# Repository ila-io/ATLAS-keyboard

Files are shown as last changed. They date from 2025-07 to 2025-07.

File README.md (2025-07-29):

# ATLAS-keyboard
A custom low profile split keyboard designed for hack club highway! It has 33 keys on each side for a total of 66, and uses one these awesome open source [mouse wheel style encoders](https://github.com/Taro-Hayashi/THQWGD0010) by Taro Hayashi on each side for navigating text (they act as arrow keys, with the one on the left as an up and down, and the one on the right is left and right). The case also has a super minimal and low profile plateless design with no top frame that leaves the cool part of the PCB uncovered, and keeps the keys nice and low on my desk. It also features a system for creating adjustable tenting angles, which is nice because I'd like to find what works best for me comfort-wise! 
i named it atlas becasue umm uhh it'll help me with text navigation? (ok this is a stretch, i just like the word) 

# Overview
In exploring split keyboard layouts, I found that not many of them had all the keys that I wanted, and the ones that did had crazy layouts and sizes. I struck a balance between the two, minimizing the size of my keyboard by making it as low profile as possible and limiting it to only the keys that I wanted.

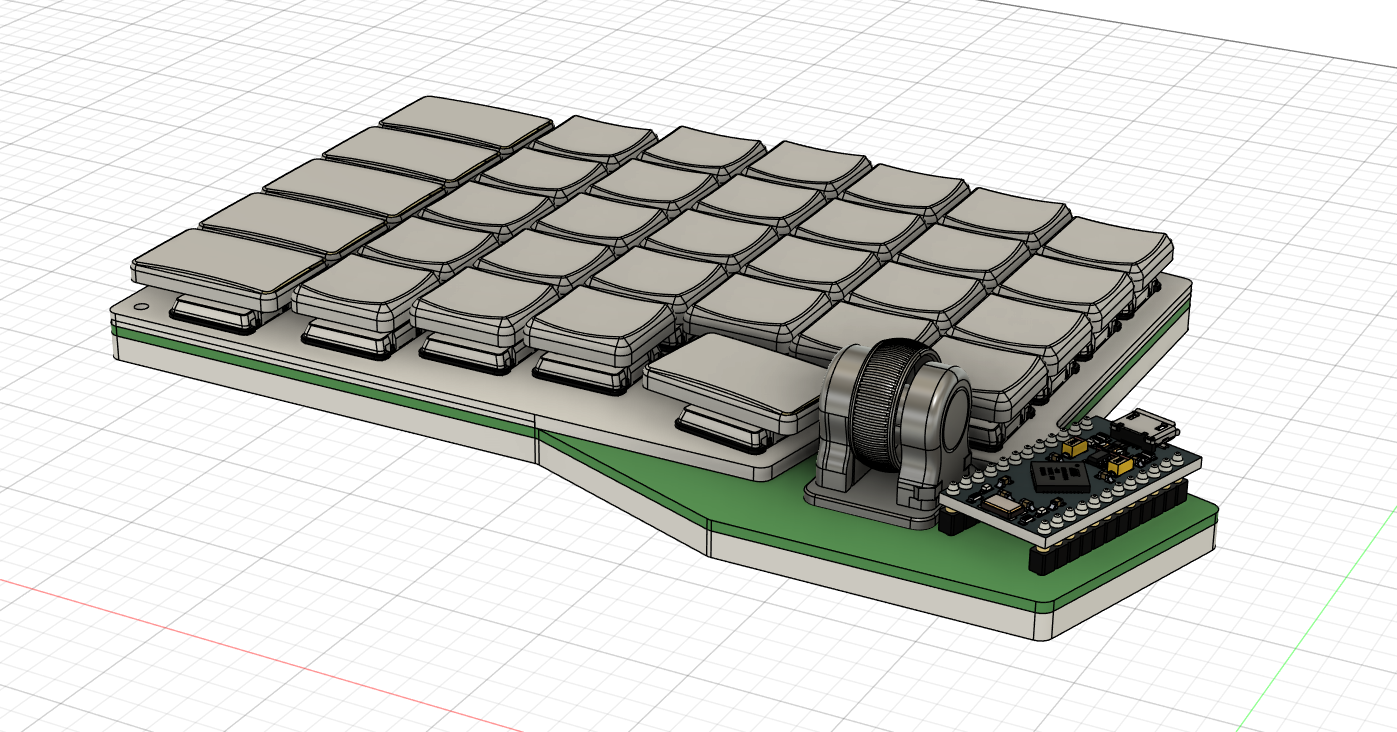
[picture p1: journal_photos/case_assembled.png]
photo of full keyboard

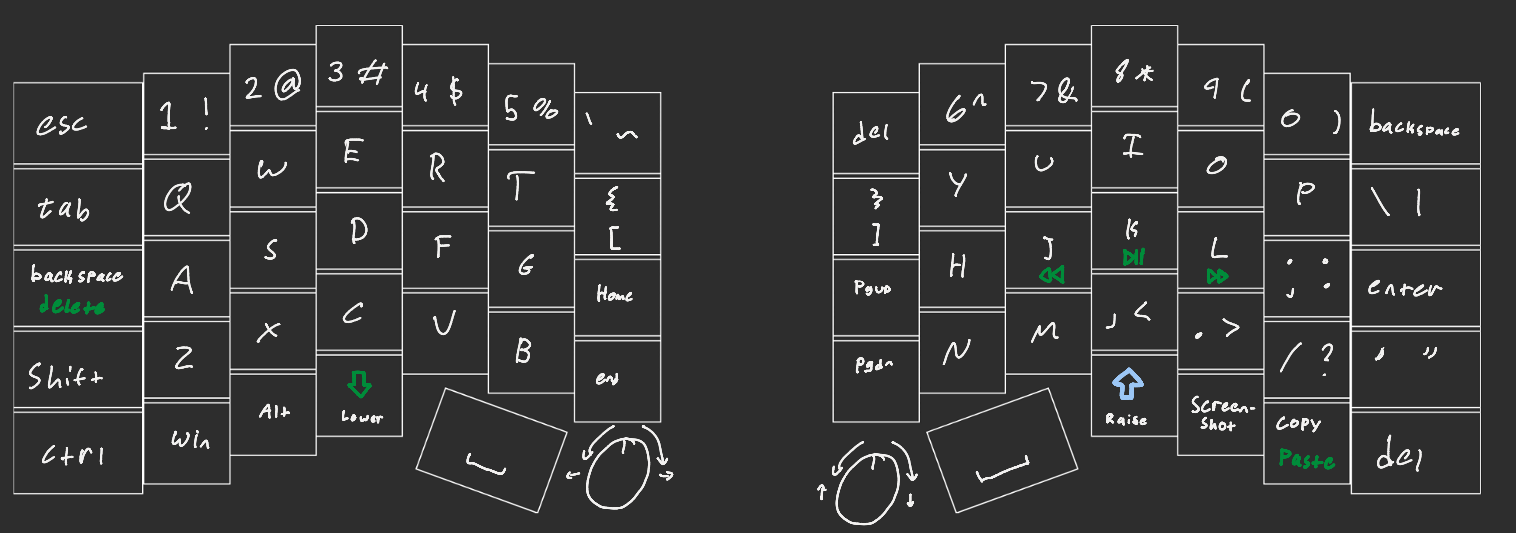
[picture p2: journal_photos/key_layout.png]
photo of keyboard layout

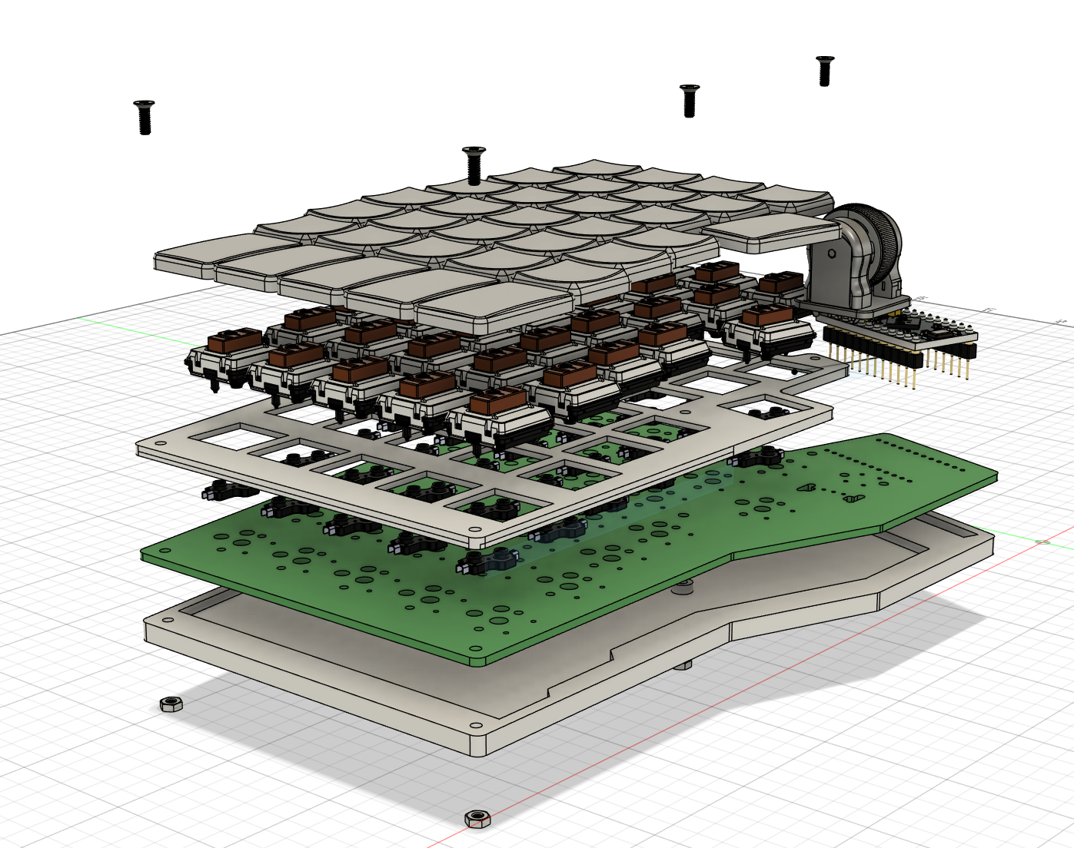
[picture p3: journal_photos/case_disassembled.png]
photo of full keyboard disassembled

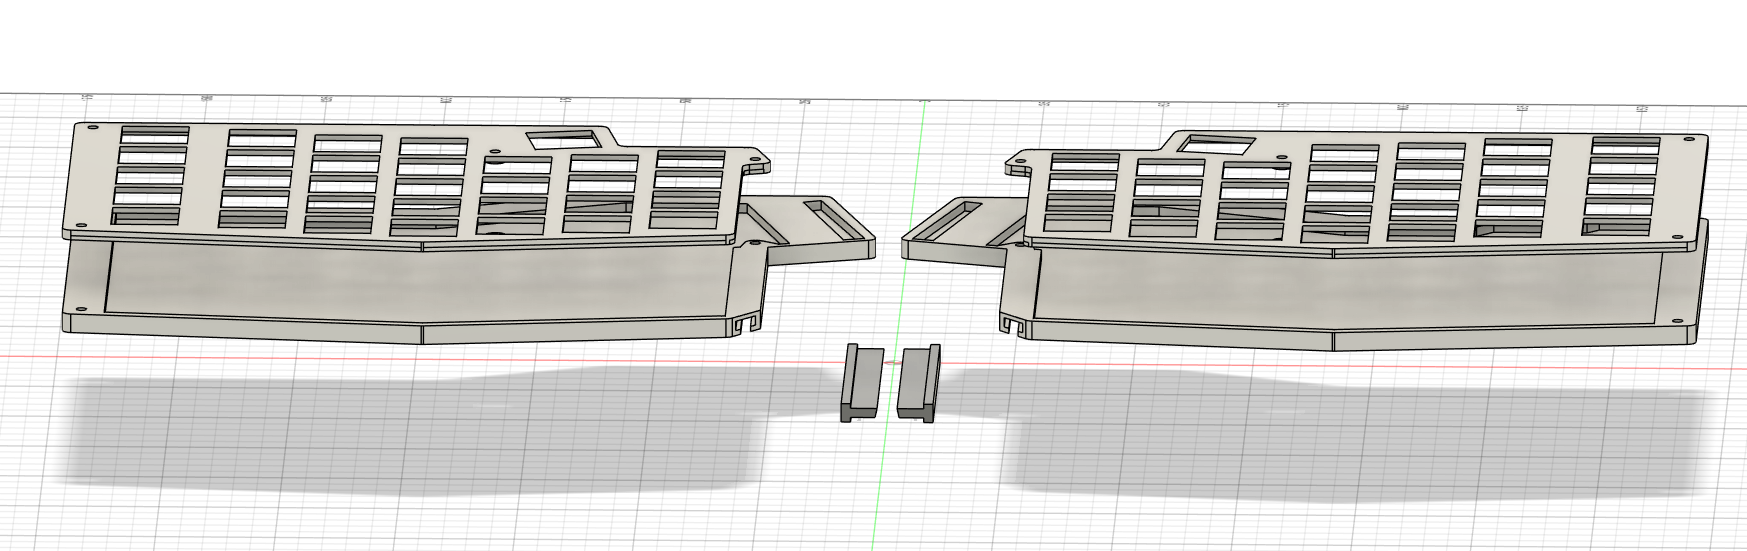
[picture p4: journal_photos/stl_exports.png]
photo of parts to print

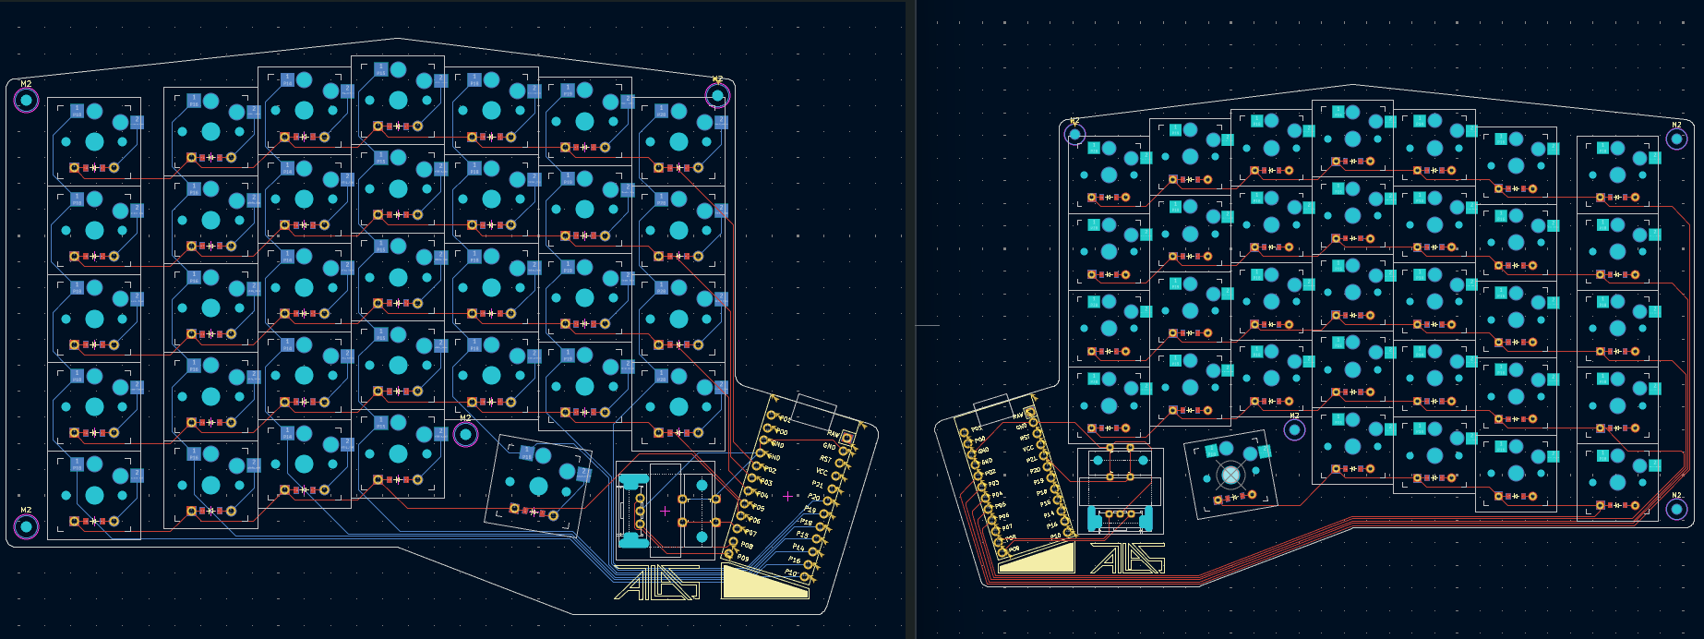
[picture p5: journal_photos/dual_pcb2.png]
photo of left and right PCBs

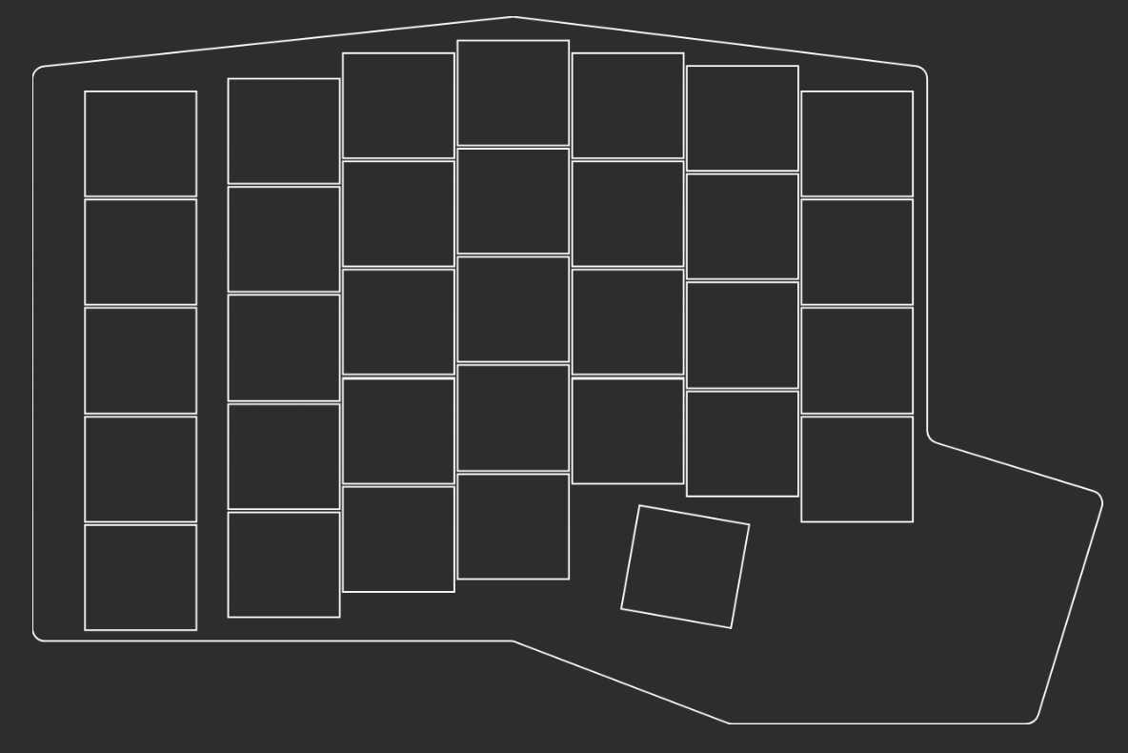
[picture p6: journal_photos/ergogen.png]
photo of ergogen generation

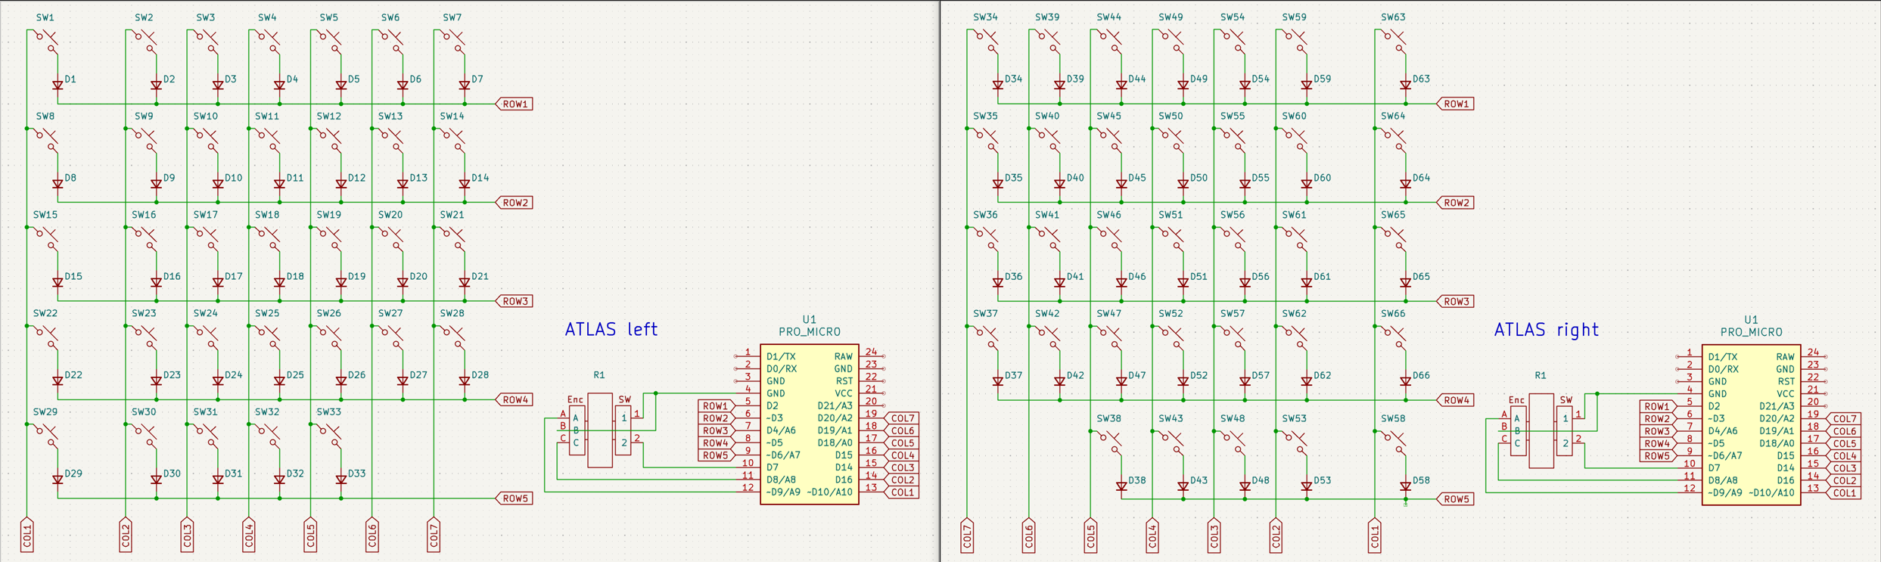
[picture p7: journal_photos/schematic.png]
photo of schematic

### NOTE:
PCB designs are based off of the PCB files/config.yaml Ergogen file, schematics are only used as reference.

## BOM 

|Item |Count|Total Cost|Source |Link |Notes |
|---|-----|---|---|---|---|
|Choc 1u Keycaps x10 |6 |$21.00 |typeractive|https://typeractive.xyz/products/mbk-keycaps?variant=45419753111783  | |
|Choc 1.5u Keycaps x2 |6 |$9.00 |typeractive|https://typeractive.xyz/products/mbk-keycaps?variant=48512019333351  | |
|Choc v1 Red Switches x10 |8 |$44 |typeractive|https://typeractive.xyz/products/choc-switches?variant=45741919240423|A little more expensive than some alternatives, but free shipping brings it below all others|
|Kailh Low Profile Hotswap Sockets x100|1 |$0.99 |aliexpress |https://www.aliexpress.us/item/3256803389452947.html |First time discount |
|1N4148W SMD Diodes x100 |1 |$1.37 |aliexpress |https://www.aliexpress.com/item/3256806137153769.html | |
|M2x6mm screws x50 |1 |$1.74 |aliexpress |https://www.aliexpress.com/item/2255801062616407.html?mp=1 | |
|M2 Hex Nuts x50 |1 |$1.51 |aliexpress |https://www.aliexpress.com/item/3256807407546447.html?mp=1 | |
|6x6x7 Tactile Button Switch x100 |1 |$2.07 |aliexpress |https://www.aliexpress.com/item/3256803858853331.html?mp=1 | |
|11mm Mouse Encoder x10 |1 |$1.56 |aliexpress |https://www.aliexpress.com/item/3256801290854651.html?mp=1 | |
|left PCB x5 + right PCB x5 + shipping |1 |$29.65 |JLCPCB |https://www.jlcpcb.com/ | |
|Atmega32U4 Pro Micro Board Module x3  |1 |$19.88 |amazon |https://a.co/d/17oYyaQ |even though there are 3 of them, when considering shipping this is the best deal i could find on even 2 |
|Total: | |$132.77 | | | |

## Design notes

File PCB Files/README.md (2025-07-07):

# NOTE:
The .kicad_sch schematic files are for reference only, the PCB files are not directly pulled from them. They are generated by the config.yaml [ergogen](https://github.com/ergogen/ergogen) file

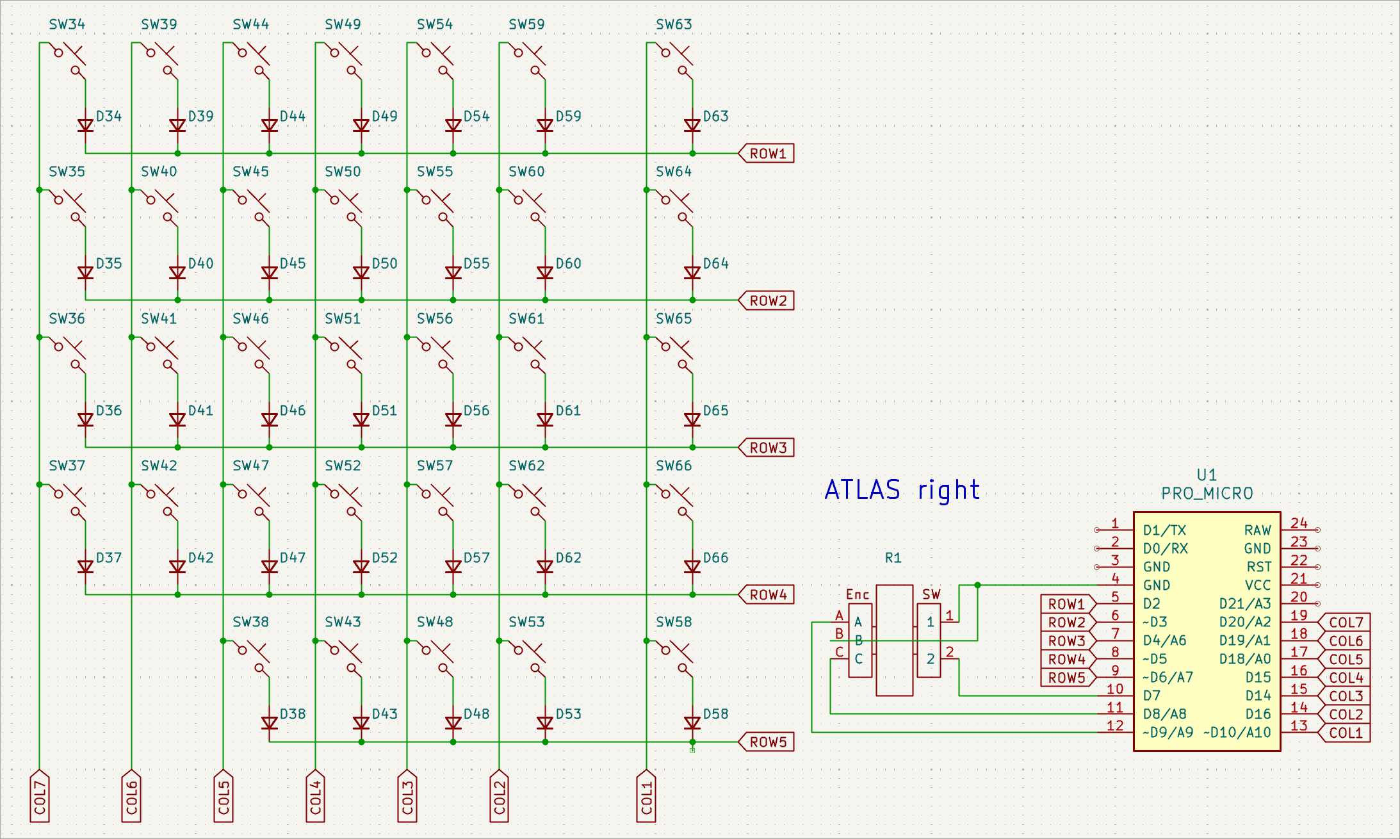
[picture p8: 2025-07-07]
journal_photos/schematic_right.png

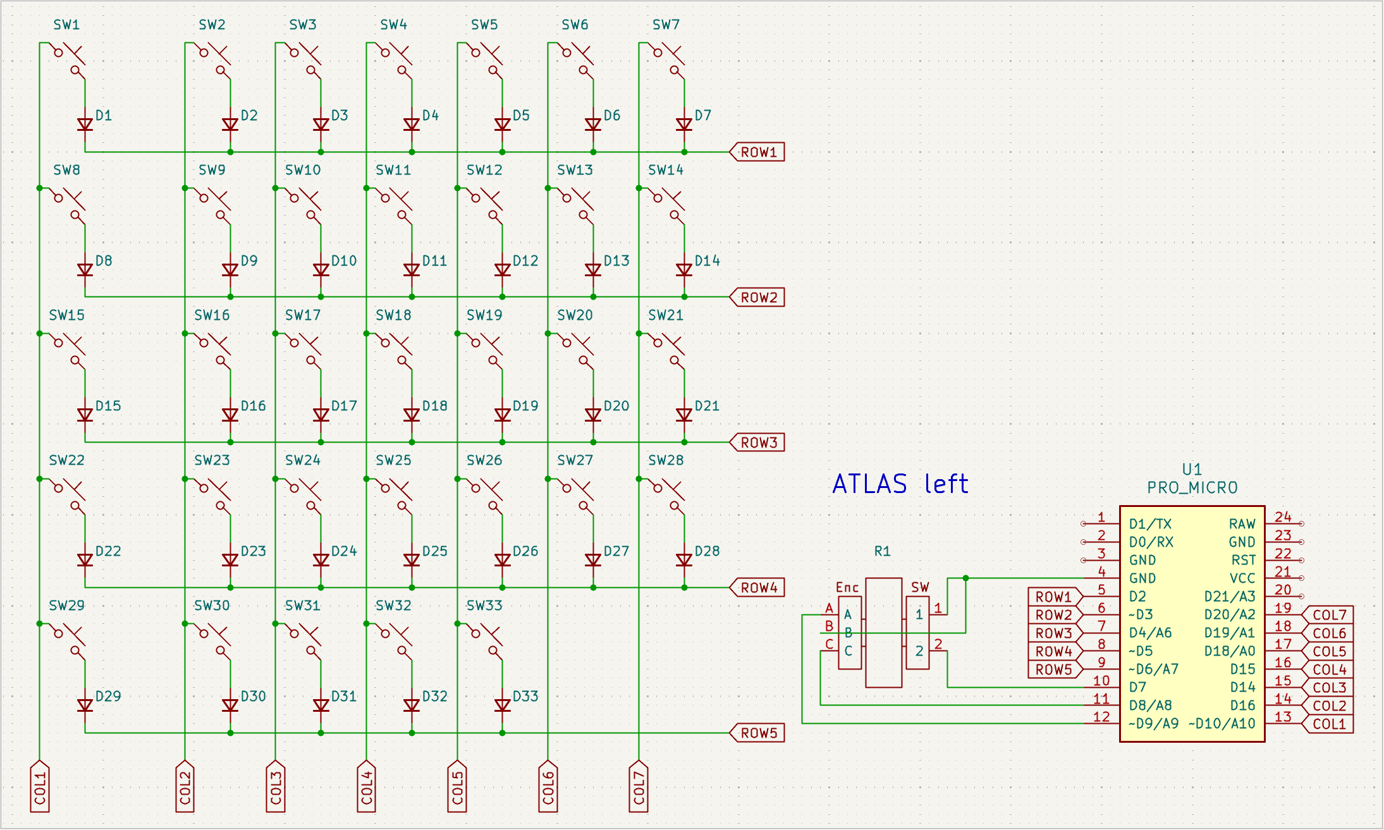
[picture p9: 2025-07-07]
journal_photos/schematic_left.png

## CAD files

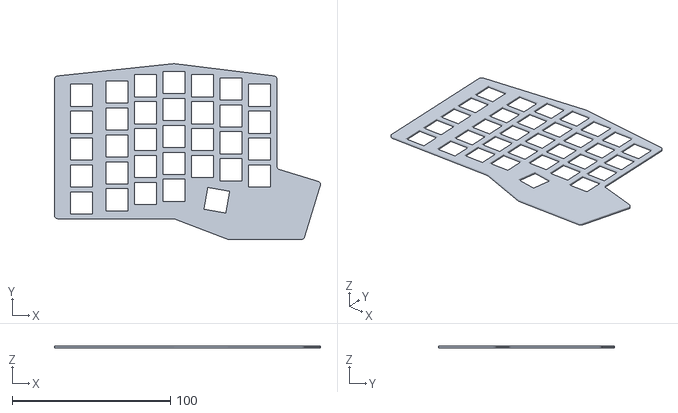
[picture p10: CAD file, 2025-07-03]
CAD Files/Components/plate.stl
168.0 x 111.0 x 1.20

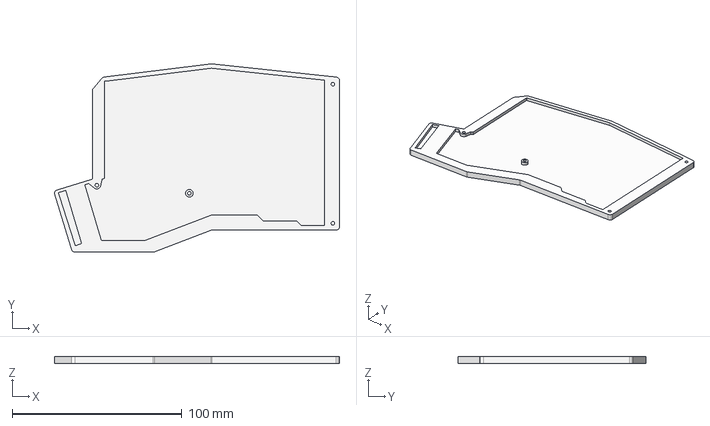
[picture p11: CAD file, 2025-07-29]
production/CAD/right_case.step
168.0 x 111.0 x 4.00 mm

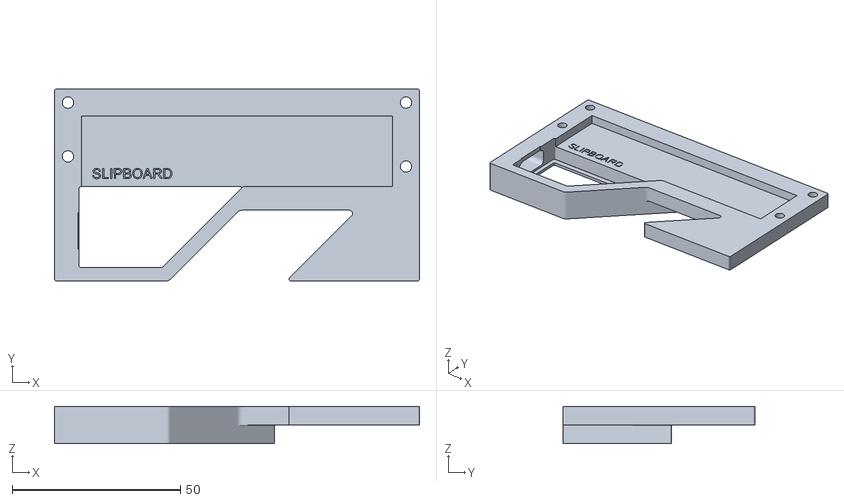
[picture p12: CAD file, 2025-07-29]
production/CAD/STLs/Case Base.stl
108.5 x 57.0 x 11.0

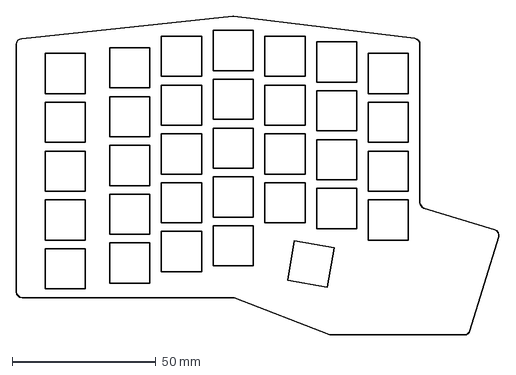
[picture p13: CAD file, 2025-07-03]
CAD Files/Components/key_cutouts.dxf
168.2 x 111.0 mm

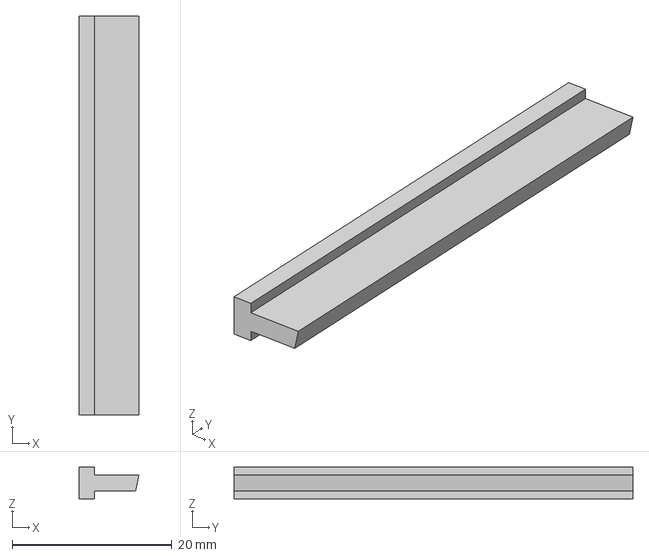
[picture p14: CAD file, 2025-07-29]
production/CAD/left_kickstand.step
7.50 x 50.0 x 3.96 mm

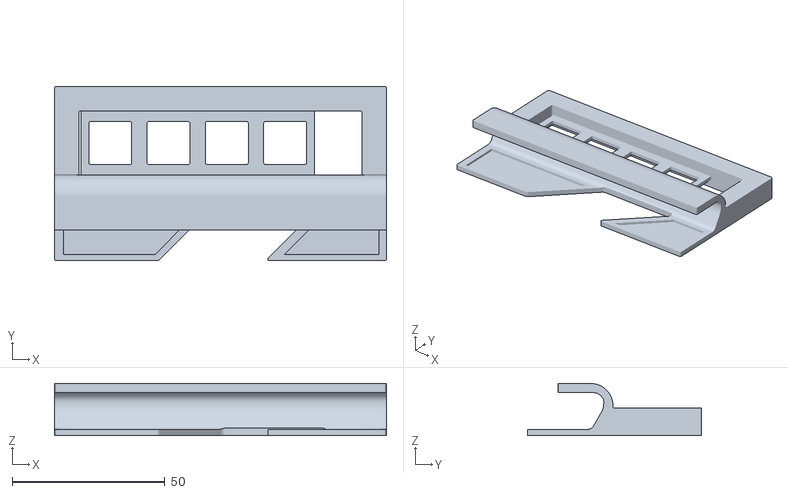
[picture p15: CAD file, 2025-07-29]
production/CAD/STLs/Case Top.stl
108.5 x 57.0 x 17.0

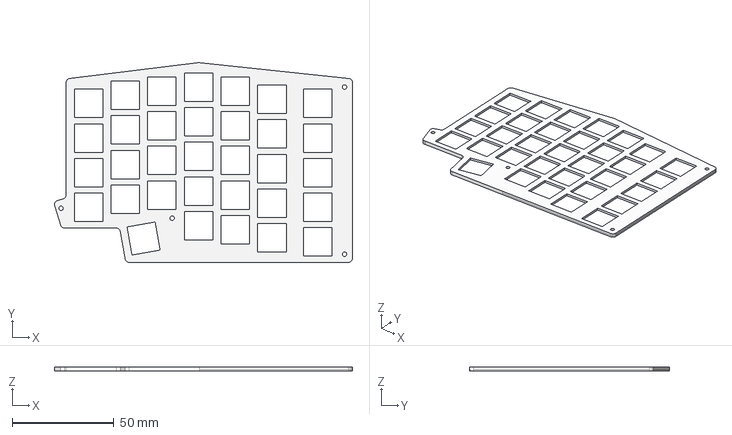
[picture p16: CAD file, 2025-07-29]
production/CAD/right_plate.step
146.2 x 98.0 x 2.10 mm

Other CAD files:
production/CAD/left_plate.step
production/CAD/right_kickstand.step
production/CAD/left_case.step
production/CAD/STLs/left_case.stl
production/CAD/STLs/left_kickstand.stl
production/CAD/STLs/left_plate.stl
production/CAD/STLs/right_case.stl
production/CAD/STLs/right_kickstand.stl
production/CAD/STLs/right_plate.stl

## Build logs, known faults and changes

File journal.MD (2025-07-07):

---
title: "ATLAS Keyboard"
author: "Colin"
description: "A 66 key super low profile split keyboard!"
created_at: "2025-06-29"
---

Total Time Spent (review 1): 34 hrs
Total Time Spent (review 2): 36 hrs

## June 29th
today i did some research into split keybaord layouts and tools for designing them. i learned how to use [Ergogen](https://github.com/ergogen/ergogen) to define a keyboard layout and designed this! i'm gonna use choc switches and low profile keycaps, and try to give the keyboard a clean, industrial look. 

This is the current layout ive settled on, but it'll 100% change once i get it and start typing on it :3

layout of keyboard

### time spent: 5 hrs
(i am a very slow worker and incredibly indecisive lol) 

## July 1st
i figued out how to use outlines in ergogen, and that allowed me to create this outline for the keyboad: 
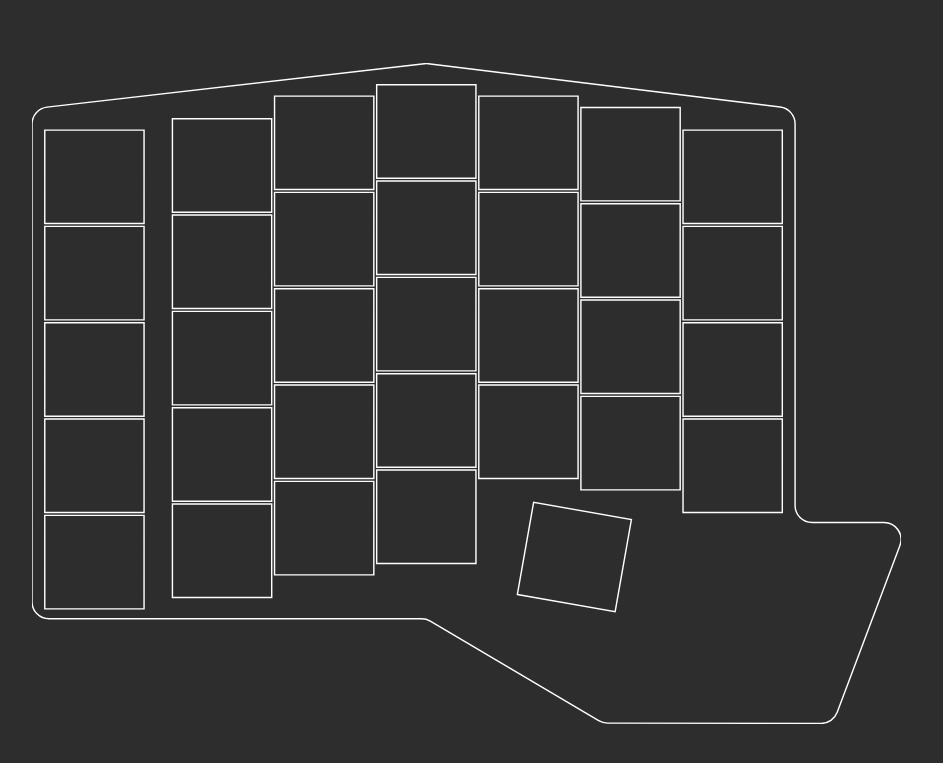
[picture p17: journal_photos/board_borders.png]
layout of left half of keyboard plus borders
 

i also learned how to turn the Ergogen yaml file into a KiCAD pcb and with a microcontroller, switches, and diodes, and automate the creation of the matrix net (?) so i dont have to do it all in a schematic! (for me as a first timer, this was 100% slower than it would have been to do manually in a schematic in KiCAD, but i was already too far in and now if i want to make another keyboard in the future, i know how to do it in a way that i can rapidly iterate :D )

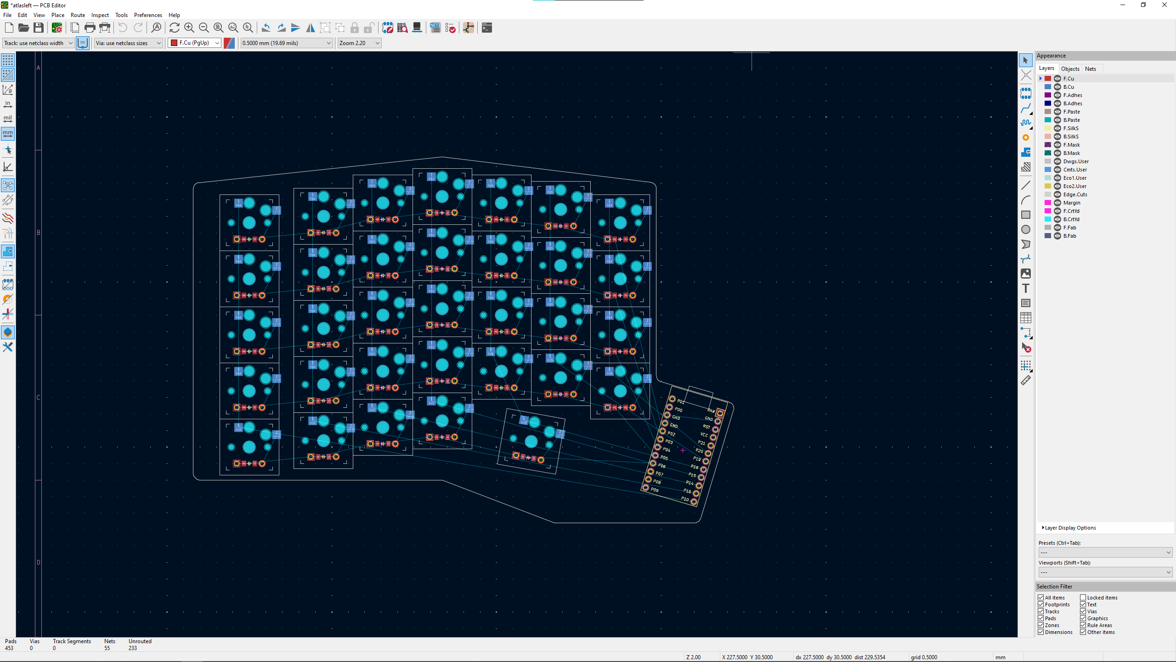
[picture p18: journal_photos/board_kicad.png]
screenshot of the board imported into KiCAD


tomorrow im going to add the rotary encoders, and route the whole pcb ! 
### time spent 5 hrs

## July 2nd
i found this super cool diy scroll-wheel style encoder that will make it a lot easier to use with 1 thumb to navigate text than an ec11 style encoder! (i'm hoping using these is allowed since its a super small part of the project, and i don't own a 3d printer so iterating something like this to a workable state would be an absolute nightmare (if not ill just swap them out with some (less usable + more expensive) ec11 encoders))

anyways, i made a few tiny changes to the outline on the ergogen file, got it to _actually_ make the matrix for me, and finished routing the left half of the pcb and i think it looks pretty good :) ill do the right half tomorrow hopefully 
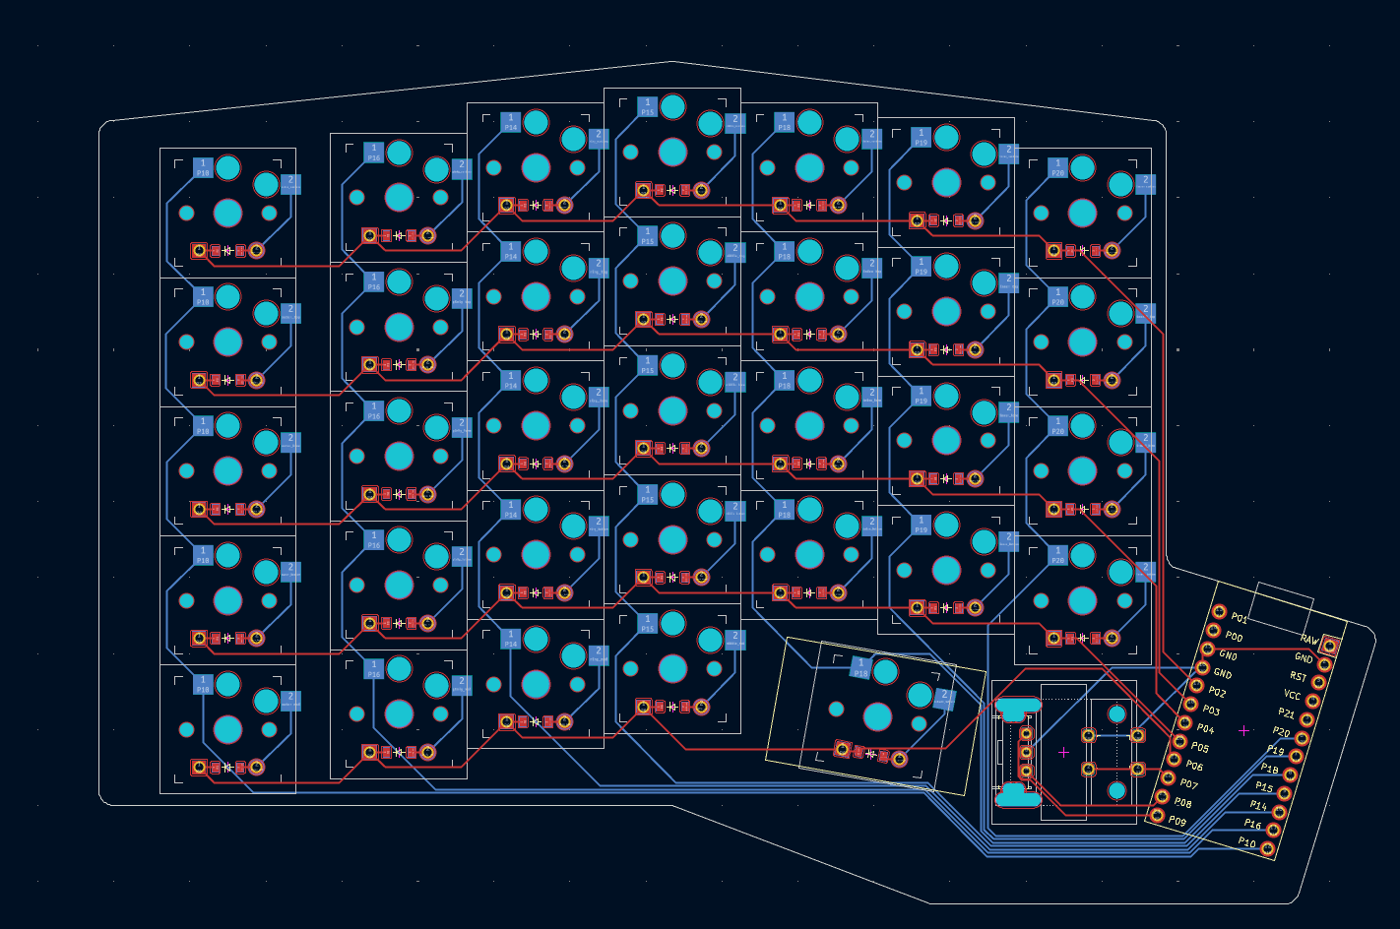
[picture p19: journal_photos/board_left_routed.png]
photo of the left half of my keyboard routed

### time spent: 6 hrs

## July 3rd 
huge day today
i finished routing the right half of the board and made some minor changes to some of the parts (added mounting holes, normalized microcontroller location, created a minor design for the silkscreen) 
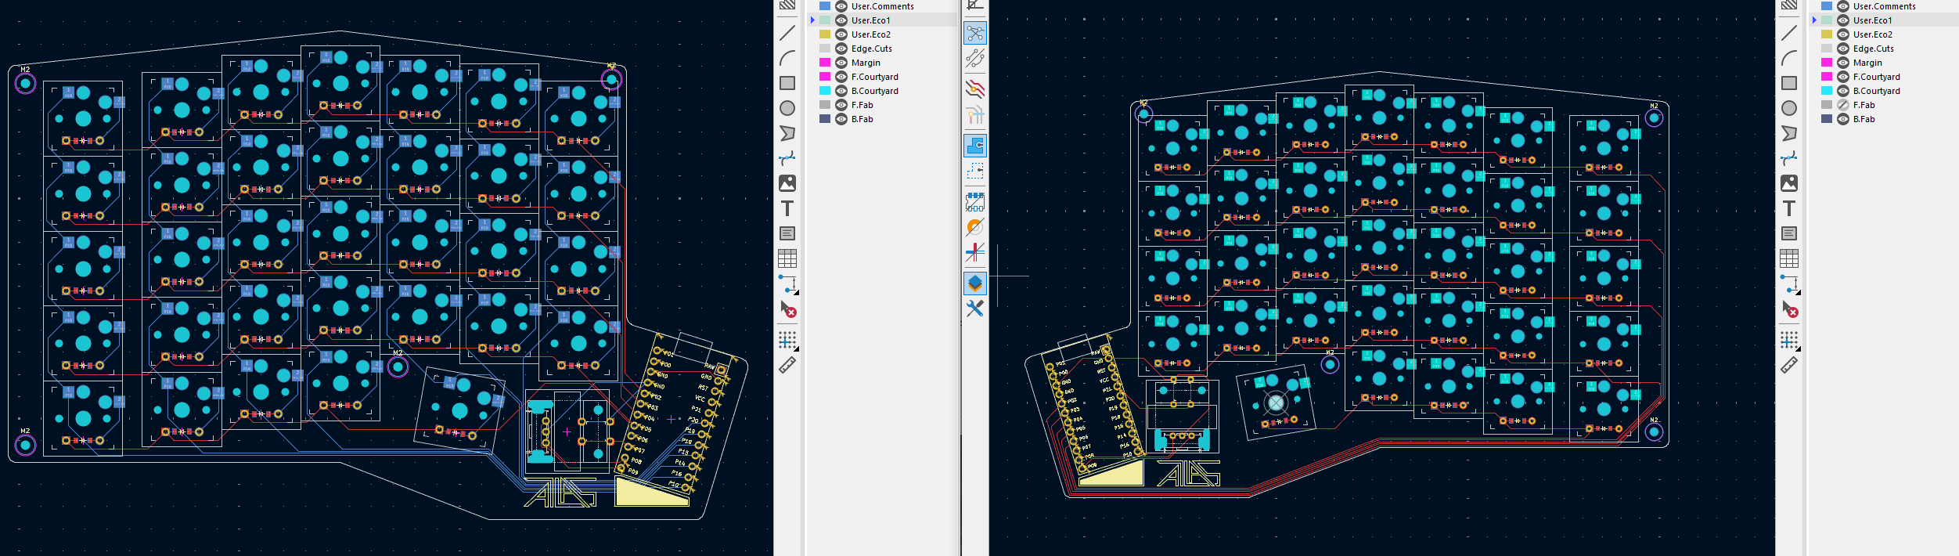
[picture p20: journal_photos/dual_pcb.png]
photo of both sides of my pcb


then i figured out how to use ergogen to export a dxf for the plate, and imported that to fusion and began modeling a case. my initial design totally flopped so that was like 4 of my hours today lol 

anyways, heres the case i ended up going with. Its a sandwich mount without the top frame in order to keep this keyboard super low profile. 
photo of my assembled case
photo of my disassembled case

here's the stl's i exported that i plan on printing, i added a little channel on the side that i can slide stands into to adjust the tent angle in the future if i want since thats something that's important to me. 
photo of my exported stl's

finally, i created a BOM and added a bunch of relevant files to this repo :)

### time spent: 14 hrs

## July 4th and 5th
Not a lot to report, just wrote the qmk firmware for each half of the keybaord, and made a readme :3
I think im about ready to submit!!

no photos for today since they would just be screenshots of vscode, and you can see exactly what i did in ./firmware! 

### time spent: 4 hrs 

## July 7th
created reference schematic files, since my reviewer asked for them
schematic
## time spent: 2 hrs

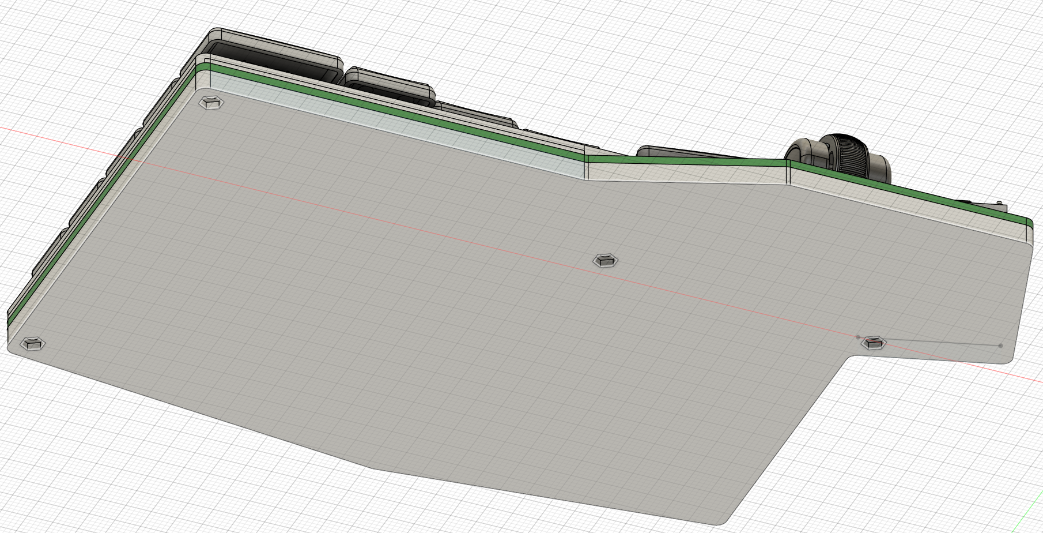
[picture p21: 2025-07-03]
journal_photos/case_bottom.png

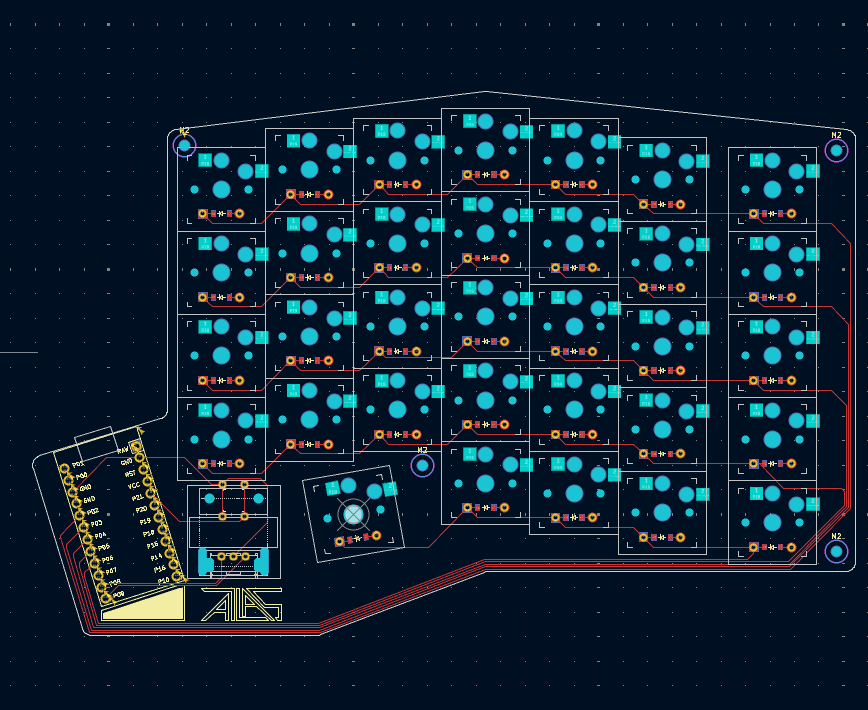
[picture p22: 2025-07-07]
journal_photos/right_pcb_finished.png

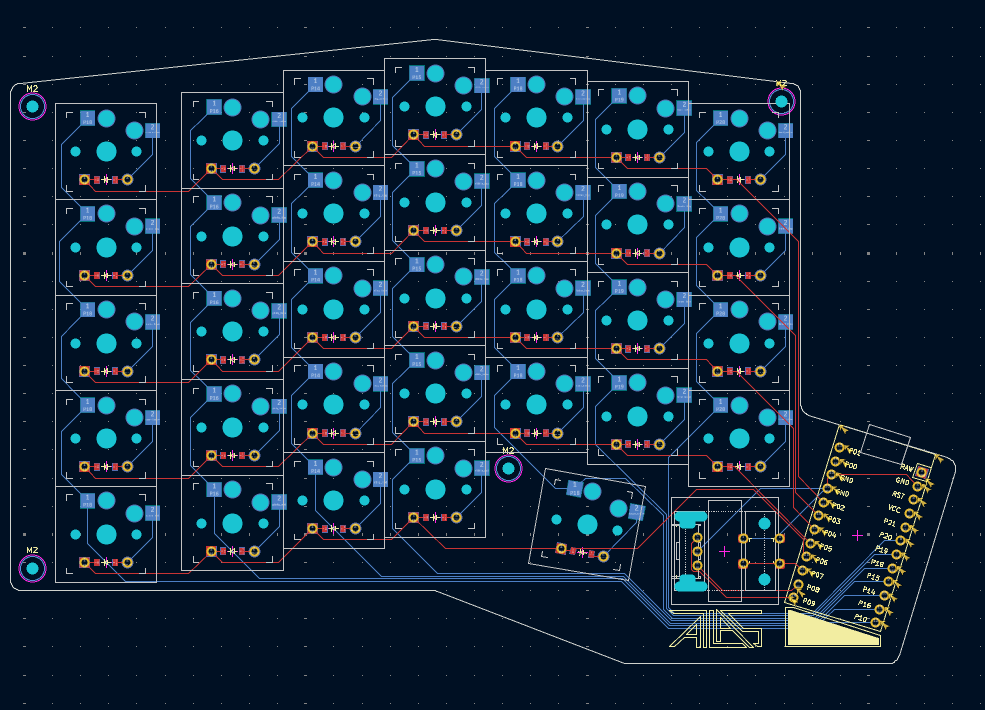
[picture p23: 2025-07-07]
journal_photos/left_pcb_finished.png

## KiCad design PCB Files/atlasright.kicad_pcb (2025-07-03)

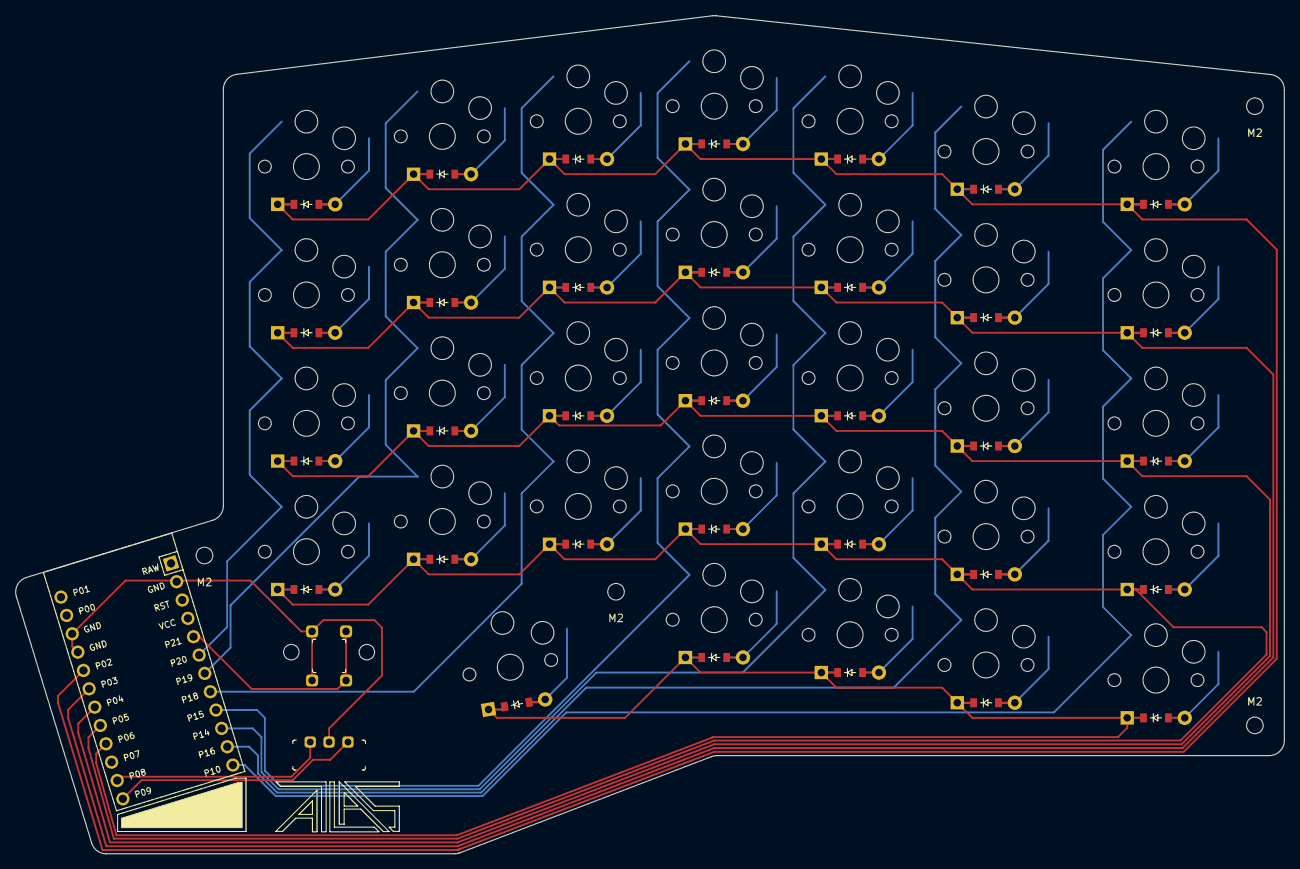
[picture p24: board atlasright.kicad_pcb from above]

Board: 2 copper layers, 168.0 x 111.0 mm, 71 parts (0 on the bottom side), 46 nets.

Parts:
D1, D2, D3, D4, D5, D6, D7, D8, D9, D10, D11, D12, D13, D14, D15, D16, D17, D18, D19, D20, D21, D22, D23, D24, D25, D26, D27, D28, D29, D30, D31, D32, D33: ComboDiode
M2, M2#2, M2#3, M2#4: MountingHole_2.2mm_M2
MCU1: ProMicro
S1, S2, S3, S4, S5, S6, S7, S8, S9, S10, S11, S12, S13, S14, S15, S16, S17, S18, S19, S20, S21, S22, S23, S24, S25, S26, S27, S28, S29, S30, S31, S32, S33: PG1350

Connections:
GND: MCU1.2, MCU1.15, MCU1.16
P2: D5.1, D10.1, D15.1, D20.1, D24.1, D28.1, D32.1, MCU1.17
P3: D4.1, D9.1, D14.1, D19.1, D23.1, D27.1, D31.1, MCU1.18
P4: D3.1, D8.1, D13.1, D18.1, D22.1, D26.1, D30.1, MCU1.19
P5: D2.1, D7.1, D12.1, D17.1, D21.1, D25.1, D29.1, MCU1.20
P6: D1.1, D6.1, D11.1, D16.1, D33.1, MCU1.21
P10: MCU1.12, S1.1, S2.1, S3.1, S4.1, S5.1
P14: MCU1.10, S11.1, S12.1, S13.1, S14.1, S15.1
P15: MCU1.9, S16.1, S17.1, S18.1, S19.1, S20.1
P16: MCU1.11, S6.1, S7.1, S8.1, S9.1, S10.1
P18: MCU1.8, S21.1, S22.1, S23.1, S24.1, S33.1
P19: MCU1.7, S25.1, S26.1, S27.1, S28.1
P20: MCU1.6, S29.1, S30.1, S31.1, S32.1
mirror_default_default: D33.2, S33.2
mirror_index_bottom: D21.2, S21.2
mirror_index_home: D22.2, S22.2
mirror_index_numbers: D24.2, S24.2
mirror_index_top: D23.2, S23.2
mirror_inner2_bottom: D29.2, S29.2
mirror_inner2_home: D30.2, S30.2
mirror_inner2_numbers: D32.2, S32.2
mirror_inner2_top: D31.2, S31.2
mirror_inner_bottom: D25.2, S25.2
mirror_inner_home: D26.2, S26.2
mirror_inner_numbers: D28.2, S28.2
mirror_inner_top: D27.2, S27.2
mirror_middle_bottom: D17.2, S17.2
mirror_middle_home: D18.2, S18.2
mirror_middle_mod: D16.2, S16.2
mirror_middle_numbers: D20.2, S20.2
mirror_middle_top: D19.2, S19.2
mirror_outer_bottom: D2.2, S2.2
mirror_outer_home: D3.2, S3.2
mirror_outer_mod: D1.2, S1.2
mirror_outer_numbers: D5.2, S5.2
mirror_outer_top: D4.2, S4.2
mirror_pinky_bottom: D7.2, S7.2
mirror_pinky_home: D8.2, S8.2
mirror_pinky_mod: D6.2, S6.2
mirror_pinky_numbers: D10.2, S10.2
mirror_pinky_top: D9.2, S9.2
mirror_ring_bottom: D12.2, S12.2
mirror_ring_home: D13.2, S13.2
mirror_ring_mod: D11.2, S11.2
mirror_ring_numbers: D15.2, S15.2
mirror_ring_top: D14.2, S14.2

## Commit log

2025-07-03 upload a lot of files
    [BOM.csv, atlasleft.kicad_pcb, atlasright.kicad_pcb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]
2025-07-06 add firmware, readme, and f3d file
    [BOM.csv]
2025-07-07 add reference schematic files
    [atlasleft.kicad_sch, atlasright.kicad_sch]
2025-07-29 add STEP files for cad
    [Case Base.stl, Case Top.stl, left_case.step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]
